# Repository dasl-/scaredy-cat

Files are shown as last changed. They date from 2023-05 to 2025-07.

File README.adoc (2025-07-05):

# scaredy cat
:toc:
:toclevels: 5

## Background
A cat clock with a camera inside. The cat's tail and eyes move as a pendulum with every "tick". When the camera detects a face, the tail and eyes stop moving until the face is no longer in the camera view.

https://photos.app.goo.gl/FYvWjFjmNzPmTfJi7[Photos & Videos]

## Installation
. `./install/install_dependencies.sh`
. `./install/install.sh`

## Administration
There are 2 services: scaredycat_tick_controller.service and scaredycat_main.service. Services can be restarted via:
....
sudo systemctl restart scaredycat_main.service scaredycat_tick_controller.service
....
Restarting one will automatically restart the other.

Logs can be viewed via:
....
journalctl | grep SCAREDYCAT
....

link:docs/viewing_live_camera_images_over_ssh.adoc[Preview the camera footage].

## Issues we've seen before
link:docs/issues_weve_seen_before.adoc[Issues we've seen before].

## Materials
. https://www.amazon.com/gp/product/B0019IBD3U/ref=ppx_yo_dt_b_asin_title_o00_s00?ie=UTF8&psc=1[Kit Cat Klock Gentlemen The Original (Classic Black)] (These come in two sizes - small and large. Make sure you get the large [original] one)
. 3D printed models: https://github.com/dasl-/scaredy-cat/tree/main/models
. Raspberry pi 4b
. https://www.pishop.us/product/raspberry-pi-camera-module-3/[Raspberry Pi Camera Module 3]
. Servo, electromagnet, and associated control circuitry

## Mounting
You will likely get better motion of the pendulum if you mount the clock on the wall very slightly off-center. Instead of aligning the clock straight up and down (12 o'clock), mount it towards 11 o'clock (head leaning to the left). This should be an almost imperceptible angle -- don't do anything drastic. Very subtle changes in alignment can have big impacts on the pendulum motion.

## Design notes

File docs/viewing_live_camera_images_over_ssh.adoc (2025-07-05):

# Viewing live camera images over SSH 
:toc:
:toclevels: 5

## Background
If you are using Raspbian Lite, which does not come with a GUI, you may struggle to determine what images the camera is capturing. Viewing a live feed of the camera is useful for debugging.

## Setup
Viewing the live feed of camera images over SSH requires installation of https://www.xquartz.org/[XQuartz] on macOS. 
....
brew install --cask xquartz
....

## Viewing live feed
1. Open XQuartz
1. In an XQuartz terminal: `ssh -XY <user>@<pi hostname or IP>`
1. Stop the service, if it's running, so that we don't have two copies of the program running: `sudo systemctl stop scaredycat_main.service`
1. Run the program with the preview flag: `sudo ./bin/tick_controller & ; ./bin/scaredycat  --show-preview`

## Known issues

### sudo
This method of viewing live camera images doesn't seem to work with `sudo`. It fails when running in XQuartz with https://gist.github.com/dasl-/35a7a9df94a35188e2307b6e6e2fa092[this error]. So don't run with `sudo`!

### "Could not load Qt platform plugin"
You may see an error like this:
....
qt.qpa.plugin: Could not load the Qt platform plugin "xcb" in "/usr/local/lib/python3.9/dist-packages/cv2/qt/plugins" even though it was found.
This application failed to start because no Qt platform plugin could be initialized. Reinstalling the application may fix this problem.
....

Follow the advice in this https://github.com/labelmeai/labelme/issues/842#issuecomment-826481652[github comment] - that is:
....
sudo mv /usr/local/lib/python3.9/dist-packages/cv2/qt/plugins /usr/local/lib/python3.9/dist-packages/cv2/qt/plugins.bak
....

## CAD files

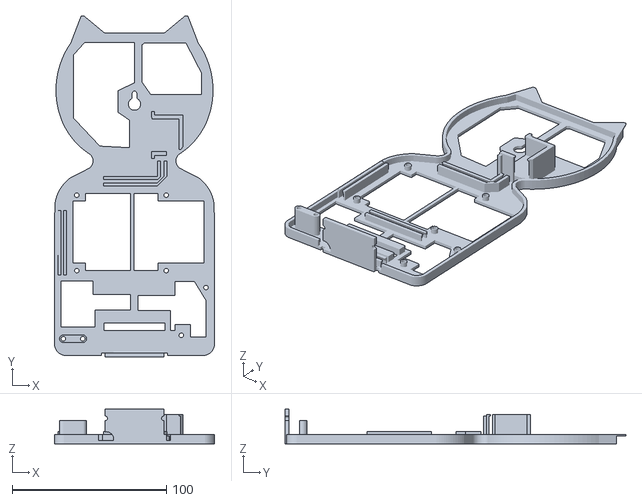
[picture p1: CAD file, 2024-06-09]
models/Cat Back-Final.stl
103.9 x 221.2 x 22.5

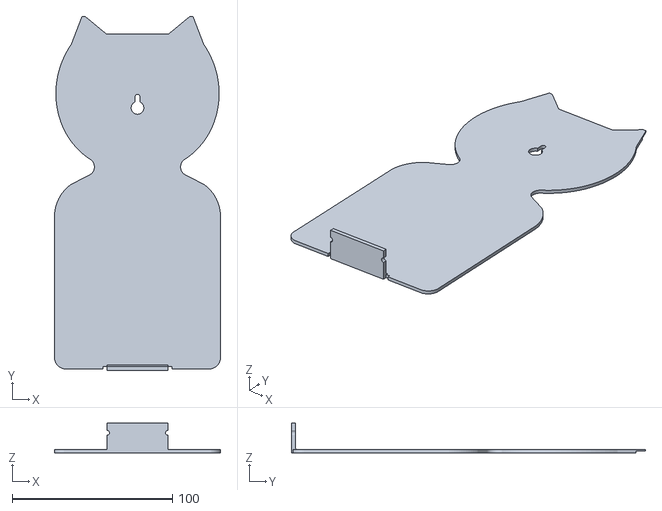
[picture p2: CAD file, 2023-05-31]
models/Cat Back - Blank.stl
103.9 x 221.2 x 18.5

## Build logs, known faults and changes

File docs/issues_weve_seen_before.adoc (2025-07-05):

# Issues we've seen before
:toc:
:toclevels: 5

## Blurry images: autofocus / focus problems
We've seen issues where the camera fails to autofocus. This is bad because the face detection is much more accurate when the image is in focus. See https://imgur.com/a/MFvspTs[this album] with a blurry photo (autofocus not working) and a sharp photo (autofocus working).

We have a script https://github.com/dasl-/scaredy-cat/blob/9fc816fa310f89b0c65ed5e2567973e254c967a3/util/focus_lens_test.py[`focus_lens_test.py`] that can help determine whether this bug is occuring. Regardless of whether autofocus is working or not, the text output of the script will look identical:

....
% python3 focus_lens_test.py
[0:40:20.064622805] [1901]  INFO Camera camera_manager.cpp:297 libcamera v0.0.5+83-bde9b04f
[0:40:20.185775970] [1902]  INFO RPI vc4.cpp:437 Registered camera /base/soc/i2c0mux/i2c@1/imx708@1a to Unicam device /dev/media4 and ISP device /dev/media2
[0:40:20.185863414] [1902]  INFO RPI pipeline_base.cpp:1101 Using configuration file '/usr/share/libcamera/pipeline/rpi/vc4/rpi_apps.yaml'
[0:40:20.192994447] [1901]  INFO Camera camera.cpp:1033 configuring streams: (0) 4608x2592-BGR888 (1) 4608x2592-SBGGR10_CSI2P
[0:40:20.193609943] [1902]  INFO RPI vc4.cpp:565 Sensor: /base/soc/i2c0mux/i2c@1/imx708@1a - Selected sensor format: 4608x2592-SBGGR10_1X10 - Selected unicam format: 4608x2592-pBAA
Actual LensPosition = 0.0, file capture in file lens-position0.jpg
Actual LensPosition = 1.0, file capture in file lens-position1.jpg
...
Actual LensPosition = 15.0, file capture in file lens-position15.jpg
....

However, when autofocus is broken, all images taken by this script will be blurry. When autofocus is working, at least some images will be sharp. https://imgur.com/a/1FmBME5[Here is how images look] when autofocus is working.

Why does autofocus sometimes stop working? It may be related to the fact that our camera is mounted on a tilt:

. https://forums.raspberrypi.com/viewtopic.php?t=372604
. https://forums.raspberrypi.com/viewtopic.php?t=350405

The first thread has a potential workaround. I've not tried it yet. Instead, when I notice that autofocus isn't working, I gently push the camera lens with a small screwdriver while viewing the live camera preview.

After a bit of jiggling, autofocus may come back to life. I'm not sure how long this fixes the issue for, i.e. how often will I have to jiggle the lens?

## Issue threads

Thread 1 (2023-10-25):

Fix fiddly dependency between the two services

dasl-, 2023-10-25:
The watchcat_motor service must be running before watchcat_main can start - the former creates a socket that the latter connects to. We tried to encode this dependency in the systemd unit file, but sometimes watchcat_main tries to start and fails because watchcat_motor was not yet ready. Most of the time it works though, so trying again usually solves it. But we should make this more robust.

Closed 2025-07-04.

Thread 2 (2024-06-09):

frame adjustment

dasl-, 2024-06-09:
1. move the black bars such that someone standing directly in front is centered
2. see if we can adjust the angle at which the camera is pointing. Will require more hot glueing

dasl-, 2025-07-05:
Fixed in https://github.com/dasl-/scaredy-cat/commit/9935d9e1cb3ef56422423f09d3067f8374235111

Closed 2025-07-05.

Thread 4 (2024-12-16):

fix false positives

dasl-, 2024-12-16:
in the afternoon when the sun shines in the right spot, the camera incorrectly sporadically detects the jackets hanging on the coat rack as faces.

[Yunet](https://github.com/opencv/opencv_zoo/tree/main/models/face_detection_yunet) says:
> This model can detect faces of pixels between around 10x10 to 300x300 due to the training scheme.

I believe the faces detected in normal locations are ~30 to ~100 px width/height. Maybe if we double the image resolution, we can get faces that are twice as big in pixels, which might result in more accurate detection?

Closed 2025-05-22.

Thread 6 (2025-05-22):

improve false positives

dasl-, 2025-05-22:
only detect if face center of mass is in the middle of the bounding box

Have different clamp on and clamp off thresholds for all params.
* face center of mass should be stricter for initial detection than for subsequent continuations
* face min width/height should likewise be stricter for initial detection
* face detection score likewise.

dasl-, 2025-07-05:
Fixed  in https://github.com/dasl-/scaredy-cat/commit/9935d9e1cb3ef56422423f09d3067f8374235111

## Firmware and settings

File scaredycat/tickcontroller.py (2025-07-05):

import atexit
import pigpio
import RPi.GPIO as GPIO
import traceback
import time

from scaredycat.unixsockethelper import UnixSocketHelper
from scaredycat.logger import Logger

SERVO_PIN = 18 # Use this pin to tell the servo to hold or release the pendulum
MAGNET_PIN = 23 # Use this pin to tell the electromagnet to turn on or off

SERVO_PAUSE_POSITION = 1000
SERVO_UNPAUSE_POSITION = 790

class TickController:

    PAUSE_SIGNAL = 'pause'
    UNPAUSE_SIGNAL = 'unpause'
    UNIX_SOCKET_PATH = '/tmp/motor_unix_socket'

    def __init__(self):
        self.__logger = Logger().set_namespace(self.__class__.__name__)
        self.__logger.info("Starting tick controller...")

        atexit.register(self.__cleanupGPIO)
        self.__pwm = self.__setupGpio()

        self.__acceptSocket()

        # Set initial state, including resetting position of servo and pulsing magnet.
        self.__paused = None
        self.__unpause()

    def run(self):
        while (True):
            # timeout_s = None: block until there's a message
            self.__readAndRespondToControlMessage(timeout_s = 0.5)
            if not self.__paused:
                GPIO.output(MAGNET_PIN, True) # turn magnet on
                self.__logger.debug('magnet on')
            self.__readAndRespondToControlMessage(timeout_s = 0.5)
            if not self.__paused:
                GPIO.output(MAGNET_PIN, False) # turn magnet off
                self.__logger.debug('magnet off')

    # Returns boolean: true if we read a message within the timeout, false otherwise
    def __readAndRespondToControlMessage(self, timeout_s):
        signal = None
        if self.__unix_socket_helper.is_ready_to_read(timeout_s):
            try:
                signal = self.__unix_socket_helper.recv_msg()
                self.__logger.info(f'got control message: {signal}')
            except Exception as e:
                self.__logger.error(f'Caught exception: {traceback.format_exc()}')
                raise e
        else:
            return False

        if signal == self.UNPAUSE_SIGNAL:
            self.__unpause()
        elif signal == self.PAUSE_SIGNAL:
            self.__pause()
        else:
            raise Exception(f"unknown signal: {signal}")
        return True

    def __unpause(self):
        if self.__paused is False:
            return

        self.__paused = False

        # Move the servo to release the hold on the pendulum
        # self.__pwm.set_servo_pulsewidth(SERVO_PIN, SERVO_UNPAUSE_POSITION)

        # move slowly to the unpaused position (to reduce motor volume)
        nextPosition = SERVO_PAUSE_POSITION
        while (nextPosition > SERVO_UNPAUSE_POSITION):
            self.__pwm.set_servo_pulsewidth(SERVO_PIN, nextPosition)
            nextPosition = nextPosition - 10
            time.sleep(0.005)

    def __pause(self):
        if (self.__paused):
            return

        self.__paused = True

        GPIO.output(MAGNET_PIN, False) # turn magnet off

        # Move the servo to hold the pendulum
        # self.__pwm.set_servo_pulsewidth(SERVO_PIN, SERVO_PAUSE_POSITION)

        # move slowly to the paused position (to reduce motor volume)
        nextPosition = SERVO_UNPAUSE_POSITION
        while (nextPosition < SERVO_PAUSE_POSITION):
            self.__pwm.set_servo_pulsewidth(SERVO_PIN, nextPosition)
            nextPosition = nextPosition + 10
            time.sleep(0.005)

    def __setupGpio(self):
        pwm = pigpio.pi()
        pwm.set_mode(SERVO_PIN, pigpio.OUTPUT)
        pwm.set_PWM_frequency(SERVO_PIN, 50)

        GPIO.setmode(GPIO.BCM)
        GPIO.setwarnings(False)
        GPIO.setup(MAGNET_PIN, GPIO.OUT)

        return pwm

    def __acceptSocket(self):
        self.__unix_socket_helper = UnixSocketHelper()
        socket = UnixSocketHelper().create_server_unix_socket(self.UNIX_SOCKET_PATH)
        self.__unix_socket_helper.set_server_socket(socket)

        self.__logger.info('Waiting to accept socket...')
        try:
            self.__unix_socket_helper.accept()
        except Exception as e:
            self.__logger.error(f'Caught exception: {traceback.format_exc()}')
            raise e
        self.__logger.info('Socket accepted!')

    # is this necessary?
    def __cleanupGPIO(self):
        GPIO.cleanup()

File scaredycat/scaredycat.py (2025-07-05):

import picamera2
import time
import cv2
import libcamera
import os
import traceback
import numpy as np

from scaredycat.logger import Logger
from scaredycat.unixsockethelper import UnixSocketHelper
from scaredycat.tickcontroller import TickController

# See specs for raspberry pi camera module 3:
# https://www.raspberrypi.com/documentation/accessories/camera.html#hardware-specification
#
# See picamera2 library docs:
# https://datasheets.raspberrypi.com/camera/picamera2-manual.pdf
class ScaredyCat:

    __NUM_CONSECUTIVE_FACE_FRAMES_TO_CONFIRM_FACE = 1
    __NUM_CONSECUTIVE_EMPTY_FRAMES_TO_CONFIRM_EMPTY = 5

    # Set parameters for filtering which faces are allowed. INIT_* values apply to
    # the first face detected in a sequence of images and are generally more restrictive.
    # REPEAT_* values apply to subsequent images and are generally more permissive. The
    # intention is to avoid flapping -- once a face is detected, it should stay detected
    # so long as it stays in mostly the same position.

    # Minimum width and height of the detected face. When changing the width / height of the
    # captured image, it probably makes sense to adjust these proportionally -- an image
    # at twice the resolution will have the same face twice as large, all else being equal.
    # INIT > REPEAT
    __INIT_MIN_W = 24
    __INIT_MIN_H = 30
    __REPEAT_MIN_W = 18
    __REPEAT_MIN_H = 22

    # float in range [0, 1]: how confident the face detection is in a given face
    # INIT > REPEAT
    __INIT_MIN_SCORE = 0.9
    __REPEAT_MIN_SCORE = 0.4

    # float in range [0, 1]: determines the range of acceptable values for
    # the face's Gaze Percent. For example, a GAZE_RANGE of 0.50 indicates that a Gaze
    # Percent between 0.25 - 0.75 would be allowed.
    # INIT < REPEAT
    __INIT_GAZE_RANGE = 0.20
    __REPEAT_GAZE_RANGE = 0.28

    # width, height: if both width and height are set, we will set the
    #   dimensions of the captured camera image to these dimensions. The
    #   units are pixels. Using smaller dimensions will speed up face
    #   detection (the camera's native resolution is 4608x2592).
    #
    # mid_col_pct: Middle column percentage. The portion of the captured image
    #   to capture for face detection. Should be a float in (0,1]
    #
    # horizontal_offset_pct: If the camera was not perfectly aligned when mounted, we
    #   can compensate with this parameter. Should be a float in [-1,1]. Negative
    #   values shift the middle column left. Positive values shift it right. This
    #   parameter is a percentage of the width. For example, if `width = 300` and
    #   `horizontal_offset_pct = 0.1`, we will shift the middle column right 30
    #   pixels.
    #
    # Explanation of how width and mid_col_pct interact:
    # If we set mid_col_pct to 1/3, then the middle third of the image will be used.
    # For example, if `width = 300`, we will use the middle 100 pixels of the captured
    # image. If you think of the image as divided into 3 columns, we will be using the
    # middle column.
    #
    # show_preview: if True, we will send a live feed of the captured
    #   images via SSH X11 forwarding.
    def __init__(self, width=None, height=None, mid_col_pct=1 / 3, horizontal_offset_pct = 0, show_preview=False):
        self.__logger = Logger().set_namespace(self.__class__.__name__)
        self.__logger.info("Starting ScaredyCat...")

        self.__picam2 = picamera2.Picamera2()
        self.__num_consecutive_face_frames = 0
        self.__num_consecutive_empty_frames = 0
        self.__confirmed_face_locations = []
        self.__unconfirmed_face_locations = []
        self.__crop_x0 = None
        self.__crop_x1 = None

        self.__unix_socket_helper = UnixSocketHelper()
        self.__unix_socket_helper.connect(TickController.UNIX_SOCKET_PATH)

        # See the camera modes here:
        # https://github.com/raspberrypi/picamera2/issues/914#issuecomment-1879949316
        mode = self.__picam2.sensor_modes[1]
        main = {}
        if width is not None and height is not None:
            main = {"size": (width, height)}

        display = None # controls which streams will be shown in the preview
        if show_preview:
            display = 'main'
            self.__setup_camera_preview(width, height)

        # raw: ensure we get the full field of view even when using a small viewport. See:
        # * https://github.com/raspberrypi/picamera2/discussions/567
        # * For pi camera v1 and v2 modules, but a similar concept applies for v3 (we use v3):
        #   https://picamera.readthedocs.io/en/release-1.13/fov.html#sensor-modes
        #
        # buffer_count: this parameter is extremely important for the main loop performance! We must
        #   increase it from the default value of 1 - otherwise `picam2.capture_array()` performance
        #   would suffer. See: https://datasheets.raspberrypi.com/camera/picamera2-manual.pdf#_more_on_the_buffer_count
        #   (Sections 4.2.1.3. "More on the buffer_count" and 4.2.1.4. "More on the queue parameter")
        config = self.__picam2.create_still_configuration(
            main=main, display=display, raw={'size': mode['size']}, buffer_count=2
        )
        self.__picam2.align_configuration(config)
        self.__logger.info(f"Using aligned picam config: {config}")
        self.__picam2.configure(config)
        self.__picam2.start()

        self.__cam_img_w, self.__cam_img_h = self.__picam2.camera_configuration()['main']['size']
        self.__logger.info(f"Using cam_img_w x cam_img_h: {self.__cam_img_w} x {self.__cam_img_h}")
        self.__setup_crop(mid_col_pct, horizontal_offset_pct)

        # See information about autofocus / focus bug that could resurface:
        # https://github.com/dasl-/scaredy-cat/blob/main/docs/issues_weve_seen_before.adoc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
        self.__picam2.set_controls({
            "AfMetering": libcamera.controls.AfMeteringEnum.Auto,
            "AfMode": libcamera.controls.AfModeEnum.Continuous,
            "AfRange": libcamera.controls.AfRangeEnum.Full,
            "AfSpeed": libcamera.controls.AfSpeedEnum.Normal,
        })

        self.__logger.info("Finished starting ScaredyCat.")

    """
    A note on timing the main loop - we provide 3 timings in the logs:
    1) loop timing
    2) image capture timing
    3) face detection timing

    This inequality will be satisfied: (1) <= (2) + (3). The image capture timing (2)
    can be deceptive. Make sure to pay attention to the overall loop timing when making
    performance optimizations.

    By setting a FrameRate, we could go even faster. But the tradeoff is we'd get darker images,
    which might result in worse face detection. We haven't experimented to decide if it's
    worth the tradeoff yet: https://github.com/raspberrypi/picamera2/issues/914#issuecomment-1880177348
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

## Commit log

2023-05-31 Add STL files
    [Cat Back - Blank.stl, Cat Back - Fittings.stl]
2023-05-31 Add Initial Motor Class
2023-05-31 better motor positioning at start
2023-05-31 Motor: Add pause and unpause methods
2023-12-27 rename the 'motor' class to 'tick controller' and refactor it to work with servo and electromagnet instead of stepper motor
2023-12-30 make socket more permissive for easier debugging
2023-12-31 improve face detection, adjust servo speed
2024-01-07 optimize main loop speed:
    Before:
    Found 0 faces in image. Loop took 0.228 s. Image capture took 0.099 s. Face detect took 0.13 s.
    After:
    Found 0 faces in image. Loop took 0.092 s. Image capture took 0.028 s. Face detect took 0.063 s. Image dimensions: (252, 150, 3)
    ~60% speed improvement
    The main things here we did are:
    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
2024-01-07 reset state better when tickcontroller is restarted
    [tickcontroller.py]
2024-06-09 Added final cat back model
    [Cat Back-Final.stl]
2024-12-16 change servo positioning to not rub the pendulum
    not sure why this was necessary because nothing should have changed...
    also improve logging in main file
    [scaredycat.py, tickcontroller.py]
2025-05-05 improve face dimensions filtering to not flap when a face is borderline. Tweak another param
2025-05-06 fix camera preview bounding box size
    [scaredycat.py]
2025-07-05 docs: camera focus / autofocus bug and viewing preview
    [focus_lens_test.py]
2025-07-05 Many improvements:
    1) Implement "INITIAL" and "REPEAT" thresholds for filtering faces on several criteria:
    a) score
    b) dimensions
    c) Gaze Percent (horizontal viewing angle)
    INITIAL values apply to the first face detected in a sequence of images and are generally more restrictive. REPEAT values apply to subsequent images and are generally more permissive. The intention is to avoid flapping -- once a face is detected, it should stay detected so long as it stays in mostly the same position.
    2) implement `horizontal_offset_pct` in case camera is mounted off-center horizontally. I reglued my camera so actually this parameter is no longer necessary for my use case, but it still see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
    [scaredycat.py]
